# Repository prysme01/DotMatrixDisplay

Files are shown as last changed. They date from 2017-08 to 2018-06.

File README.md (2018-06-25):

# DotMatrixDisplay

Display messages to a DOT Matrix LED Display.
Message are sent to a MQTT server from any other application, the ESP8266 is subscribing to the channel and display messages depending on few parameters (animation, intensity, ...)

###### My use case
Displaying messages in the living room from my home automation solution (jeedom).

### Prerequisites

* ESP8266 (mine is Wemos D1 NodeMcu  ESP12F)
* DOT Matrix based on MAX7219
* OLED display (SSD1306 and SH1106 based 128x64 pixel) - optional
* MQTT server somewhere - preferred on your LAN for privacy
* Temperature sensor DS18B20 - optional
* Light sensor GL5516 - optional

### Features
* Display message from a MQTT server
* NTP client for date and time
* Temperature measurement
* LED matrix dimming based on light sensor
* Read a file to display text (TODO)
* more to come

### Usage
* Make sure your DotMatrix is properly configured according to [MAX72xx](https://github.com/MajicDesigns/MD_MAX72XX) (MAX72xx.h)
* Adapt the code (parameters, MQTT ipaddress)
* Drop the code to your ESP8266, third party libraries are included
* First time the ESP8266 should act as an access point (ESPxxxx), connect to it then go to http://192.168.4.1/ to configure your WIFI SSID/Password (STORE in EEPROM), then restart
* OLED should now display your IP on your network
* HTTP Command is available and describe at http://IP/command

### MQTT 
ESP8266 is subscribing to topic "jeedom/message" and expect this json syntax
```json
{
   "text": "My TEXT ",
   "priorite": 1,
   "lum": 15,
   "pos": 2,
   "eff_in": 1,
   "eff_out": 1,
   "speed": 25,
   "pause": 1000
}
```
-- text : the message to display
-- priority : TODO
-- lum : intensity of the LCD panel (1-15)
-- pos : 0-LEFT, 1-Center, 2-RIGHT
-- speed : speed of the animation (fps)
-- pause : time between entry and exit effect
-- eff_out : exit effect (same value as eff_in)
-- eff_in : entry effect
* 0 : SCROLL RIGHT
* 1 : SCROLL LEFT
* 2 : SCROLL UP
* 3 : SCROLL DOWN
* 4 : OPENING CURSOR
* 5 : CLOSING CURSOR
* 6 : WIPE
* 7 : MESH
* 8 : FADE
* 9 : PRINT (fixed message)
* 10 : BLIND
* 11 : SCAN HORIZONTAL 0
* 12 : SCAN HORIZONTAL 1
* 13 : SCAN VERITICAL 0
* 14 : SCAN VERITICAL 1

Prototype
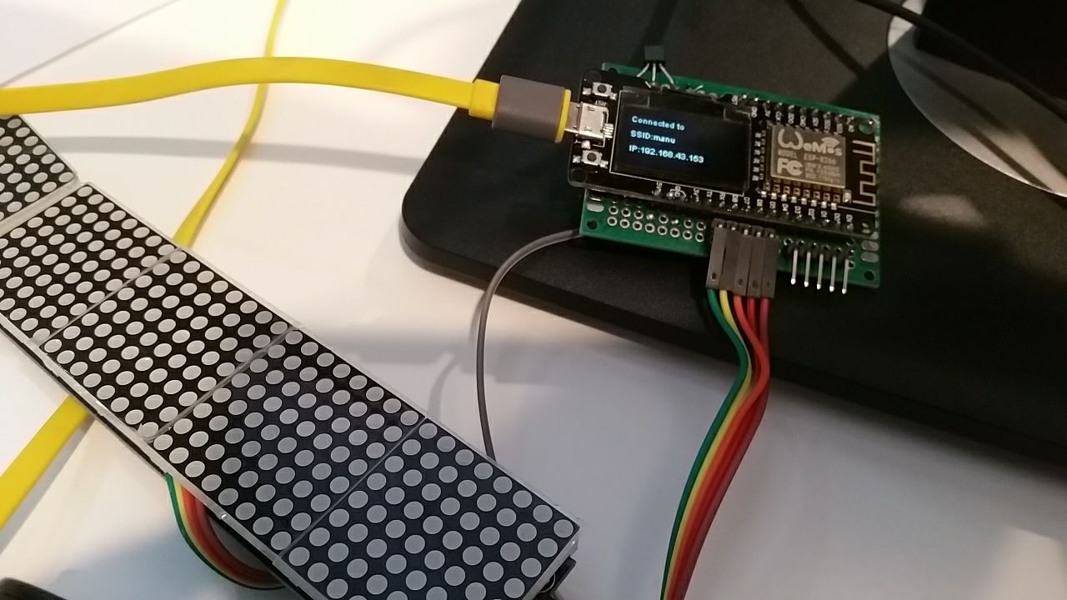
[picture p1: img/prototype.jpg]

Final and ugly soldering
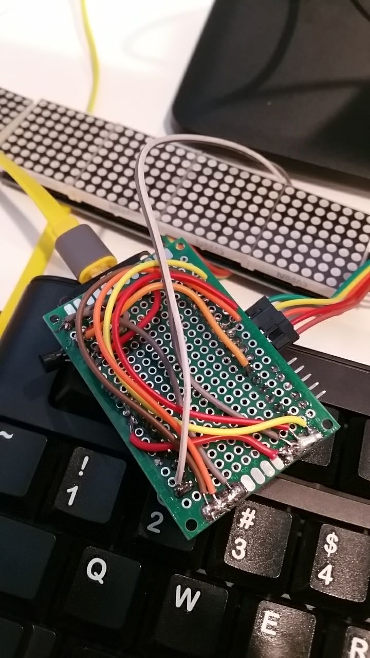
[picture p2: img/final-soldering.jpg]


SMALL VIDEO example HERE Video

### Sketch
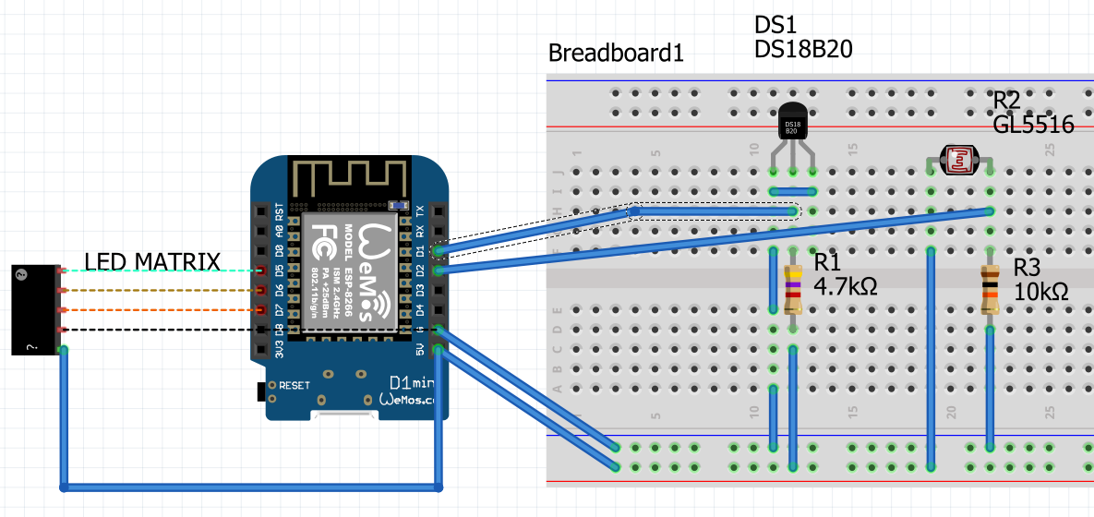
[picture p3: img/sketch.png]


The sketch is not good for the DS18B20, so check on google on how connect properly the DS18B20.
Also in the code the DS12B20 pin is set to D4 and on the image it's D1

## License

This project is licensed under the GPL License

## Acknowledgments

Thank you very much to [DIYDave](https://github.com/DIYDave/ScrollText-ESP8266) for his code and inspiration 

Libraries used, thanks to their respectives authors
* [MD_Parola](https://github.com/MajicDesigns/MD_Parola) DotMatrix management library
* [MAX72xx](https://github.com/MajicDesigns/MD_MAX72XX) Max7219 library
* [WifiManager](https://github.com/tzapu/WiFiManager) Wifi management
* [SSD1306](https://github.com/squix78/esp8266-oled-ssd1306) OLED library

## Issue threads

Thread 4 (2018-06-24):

wrong schematic?

fragolinux, 2018-06-24:
schematic seems wrong... there's no connection from ds18b20 to positive 3.3V, and there's a jumper right below it that connects vcc and gnd together... and data pin is connected to d1 in schematic, and to d4 in code...

fragolinux, 2018-06-24:
even display links are wrong between schematic and code, and the ds18b20 in code is linked to d4, in image to d1

prysme01, 2018-06-25:
yes sorry, I will remove the schematic, it has changed since and the code is not synced.

fragolinux, 2018-06-25:
so you'll republish an updated one, or at least publish a textual version in opening readme.md? thanks

Closed 2018-06-25.

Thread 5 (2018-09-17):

Support of P3 64x32 RGB LED Matrix?

hallard, 2018-09-17:
Awesome project,
It's not an issue, but I'm using JEEDOM also and got this nice [64x32 RGB LED Matrix](https://fr.aliexpress.com/item/P3-RGB-pixel-panel-HD-display-64x32-dot-matrix-p3-smd-rgb-led-module/32728985432.html) with custom adapter open sourced
https://github.com/hallard/WeMos-Matrix-Shield

Would be awesome to support this display, the library exists so may be it could be easy.
You can check out the original[project](https://www.instructables.com/id/Morphing-Digital-Clock/)

prysme01, 2018-09-17:
Hello charles,

I would be able to do it, but I need to have this matrix here to test it.
One day, maybe.

hallard, 2018-09-17:
Thanks,
Makes sense, I'm waiting for the V1.2 of my PCB adapters for this Matrix, I can send you one with a Wemos assembled if it can help to contrib ;-)

prysme01, 2018-09-17:
Sure I could work on it if you send it to me.

hallard, 2018-09-17:
Ok, get back back here when I receive the adapter boards

Closed 2019-07-29.

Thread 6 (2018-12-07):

great work but ...

bandric1, 2018-12-07:
Can you update the project it cannot be compiled with arduino when i try to compile get this error BearSSLHelpers.cpp:30:24: fatal error: StackThunk.h:

i have solved other library issues but cannot solve this one no matter what i do.

prysme01, 2018-12-07:
Hello, I don't have an arduino so this project has been done to be used on a weemos esp8266. I don't use anything in particular, but I won't be able to fix it. sorry.

bandric1, 2018-12-07:
i used arduino ide for compling i also use wemos but get that error

prysme01, 2018-12-07:
Let me check out my code and try it

bandric1, 2018-12-07:
I dont get u on this one, what do you mean?

prysme01, 2018-12-07:
I've just download a fresh Arduino IDE and my code from github it works fine.

Build options changed, rebuilding all
Sketch uses 337428 bytes (32%) of program storage space. Maximum is 1044464 bytes.
Global variables use 32304 bytes (39%) of dynamic memory, leaving 49616 bytes for local variables. Maximum is 81920 bytes.

All I've done is :
Adding a new board in Arduino IDE ( copy the following and paste into your Preferences dialog and select OK: http://arduino.esp8266.com/stable/package_esp8266com_index.json  )
Select Board Weemos D1

Copy the library folder from my code into C:\Users\esale\Documents\Arduino\libraries
Compile complain about WifiManager error, I've update the WifiManager from tzapu to 0.14.0 and it compile fine.

I don't understand where you get this error from BearSSLHelpers.

bandric1, 2018-12-07:
Ok i guess ive done some stupit things with arduino and it knocked me out.
Thanks.

bandric1, 2018-12-07:
There is one more question i use credentials to login to my mqtt. I didnt find anywhere in .ino exept the ip and topic.

prysme01, 2018-12-07:
you are right, I did not manage credentials, the topic has to be public, so no user/password.

Closed 2019-07-29.

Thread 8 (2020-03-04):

Problems with Compiling

capitaenz, 2020-03-04:
Hi,

I have already tried various things, but unfortunately no success.
I get this error when compiling:

> exit status 1
> 'PA_SCAN_HORIZ0' was not declared in this scope

I tried different versions of Arduino IDE, different versions of the libraries, ...
What else can I try?

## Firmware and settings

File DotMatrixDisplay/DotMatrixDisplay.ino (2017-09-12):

// Configure is you want to use OLED display or DEBUG to serial
// Comment option to disable
#define USE_OLED_DISPLAY 
#define USE_LIGHT_SENSOR
#define USE_DEBUG 1

#include <MD_Parola.h>          // https://github.com/MajicDesigns/MD_parola
#include <MD_MAX72xx.h>         // https://github.com/MajicDesigns/MD_MAX72XX
#include <MD_MAX72xx_lib.h>
#include <SPI.h>
#include "utf8_font.h"
//#include "utf8_tools.c"

#ifdef USE_OLED_DISPLAY
  #include <Wire.h>
  #include <brzo_i2c.h>
  #include <OLEDDisplay.h>
  #include <OLEDDisplayFonts.h>
  #include <OLEDDisplayUi.h>
  #include <SSD1306.h>
  #include <SSD1306Spi.h>
  #include <SSD1306Brzo.h>
  #include <SSD1306Wire.h>
  #include "res.h"                  // Picture resources in the sketch directory
#endif

#include <DNSServer.h>

#include <ESP8266WiFi.h>
#include <ESP8266WiFiAP.h>
#include <ESP8266WiFiGeneric.h>
#include <ESP8266WiFiMulti.h>
#include <ESP8266WiFiScan.h>
#include <ESP8266WiFiSTA.h>
#include <ESP8266WiFiType.h>
#include <WiFiClient.h>
#include <WiFiClientSecure.h>
#include <WiFiServer.h>
#include <WiFiUdp.h>
#include <WiFiManager.h>          //WiFi Configuration Magic https://github.com/tzapu/WiFiManager 
#include <EEPROM.h>               // Library for handle teh EEPROM

#include <TimeLib.h>
#include <NtpClientLib.h>

#include <OneWire.h>
#include <DallasTemperature.h>

#include <ArduinoJson.h>
#include <PubSubClient.h>

// ESP8266 PIN configuration
#define CLK_PIN   D5  // Matrix CLK
#define DATA_PIN  D7  // Matrix DIN
#define CS_PIN    D6  // Matrix DS
#define DS18B20BUS D4 // OneWire Dallas DS18B20 PIN

#define MAX_DEVICES 8 // Number of LED MATRIX module

// DS18B20 Temperature sensor
OneWire oneWire(DS18B20BUS);
DallasTemperature DS18B20(&oneWire);

long millis_temperature;                                                    // Use in the loop to store execution time
long millis_lightsensor;                                                    // Use in the loop to store execution time

// PAROLA 
uint8_t parolaCurrentType = 0;
uint8_t frameDelay = 25; // default frame delay value
//char parolaCurrentMessage[256] = "";
char parolaCurrentMessage[120];
textEffect_t parolaEffectIn;
textEffect_t parolaEffectOut;
textPosition_t parolaPosition;
int parolaAnimationSpeed;
int parolaPause;
bool parolaIntensityManagedBySensor = true;                                 // light sensor management on/off
bool newMessageAvailable = false;
int LIGHT_SENSOR_POLLING=60*1000;                                           // Wait 5 sec to adjust LED matrix intensity based on light sensor
MD_Parola parola = MD_Parola(CS_PIN, MAX_DEVICES);                          // HARDWARE SPI for dot matrix display
uint8_t pin_led = 16;

// MQTT CONFIGURATION
const char* MQTT_TOPIC_MESSAGE = "jeedom/message";                          // MQTT topic to subscribe for message
const char* MQTT_TOPIC_SENSOR  = "jeedom/ESP8266_LED_MATRIX_BOX/sensors";   // MQTT topic to publish temperature
const char* MQTT_TOPIC_SENSOR_DEVICE  = "ESP8266_LED_MATRIX_BOX";           // MQTT topic to publish temperature
const char* MQTT_CLIENT_ID ="ESP32Client";                                  // MQTT client id needed to get offline messages during reconnexion | not working mqtt lib doesnot support clean session
const IPAddress MQTT_BROKER_IP(37,187,1,120);                               // MQTT BROKER IP address
const int  MQTT_BROKER_PORT = 1883;                                         // MQTT BROKER port
const int MQTT_POLLING_SENSOR = 15*60*1000;                                 // MQTT polling delay between sending temperature to jeedom in millisec

WiFiClient wifiClient;
WiFiManager wifiManager;
PubSubClient mqttclient(wifiClient);

#ifdef USE_OLED_DISPLAY
  SSD1306Brzo  display(0x3c, D1, D2);
#endif 



uint8_t utf8Ascii(uint8_t ascii)
{
  static uint8_t cPrev;
  uint8_t c = '\0';

  if (ascii < 0x7f)   // Standard ASCII-set 0..0x7F, no conversion
  {
    cPrev = '\0';
    c = ascii;
  }
  else
  {
    switch (cPrev)  // Conversion depending on preceding UTF8-character
    {
    case 0xC2: c = ascii;  break;
    case 0xC3: c = ascii | 0xC0;  break;
    case 0x82: if (ascii==0xAC) c = 0x80; // Euro symbol special case
    }
    cPrev = ascii;   // save last char
  }

  PRINTX("\nConverted 0x", ascii);
  PRINTX(" to 0x", c);

  return(c);
}

void utf8Ascii(char* s)
{
  uint8_t c, k = 0;
  char *cp = s;

  PRINT("\nConverting: ", s);

  while (*s != '\0')
  {
    c = utf8Ascii(*s++);
    if (c != '\0')
      *cp++ = c;
  }
  *cp = '\0';   // terminate the new string
}


void configModeCallback (WiFiManager *myWiFiManager) {
  #if USE_DEBUG
    Serial.println("Entered config mode");
    Serial.println(WiFi.softAPIP());
    Serial.println(myWiFiManager->getConfigPortalSSID());
  #endif
  
  #ifdef USE_OLED_DISPLAY
    display.drawString(0, 0, "Entering Config Mode" );
    display.drawString(0, 20, "SSID:"+myWiFiManager->getConfigPortalSSID() );
    display.drawString(0, 40,"IP:" + WiFi.softAPIP().toString() );
    display.display();
  #endif

  parola.print("AP|MODE");
}

#ifdef USE_OLED_DISPLAY
/**
 * Display LOGO for 1 second (Logo is declared in res.h)
 * format XBM done with GIMP 128 pixels x 64 pixels Black and White
 */
void OLEDWelcome() {
  display.drawXbm(0 , 0, Logo_width, Logo_height, xbm_bits);
  display.display();
  delay(1000);
  display.clear();
}
#endif

/**
 * Setup code, run once a startup
 */
void setup() {
  
  #if USE_DEBUG
    Serial.begin(115200);
  #endif

  // Start DS18B20 measurement
  DS18B20.begin();

  //pinMode(A0,INPUT);
  
  //pinMode(LED_BUILTIN,OUTPUT);                        // configure the builtin led to OUTPUT mode
  //digitalWrite(LED_BUILTIN,!digitalRead(pin_led));  // switch the status (values can be LOW or HIGH)

  #ifdef USE_OLED_DISPLAY
    // OLED Init
    display.init();
    display.clear();
    //display.setContrast(55);
    display.setFont(ArialMT_Plain_10);
    display.setTextAlignment(TEXT_ALIGN_LEFT);
    OLEDWelcome();
  #endif
  
  // Dot Matrix init
  parola.begin(); 
  parola.displayClear();
  parola.displaySuspend(false);
  parola.setIntensity(5);  // Restore last intensity value saved from EEPROM
  parola.setFont(ExtASCII);
  parola.setTextAlignment(PA_CENTER);
  //parola.setCharSpacing(1);
  
  wifiManager.setAPCallback(configModeCallback);
  //wifiManager.setConfigPortalTimeout(TIMEOUT_PORTAL);
  Serial.println("Wifi.autoConnect start");
  if(!wifiManager.autoConnect()) {
    parola.displayText ("WIFI not working", PA_CENTER, 15, 1000, PA_OPENING_CURSOR , PA_OPENING_CURSOR );
    //reset and try again, or maybe put it to deep sleep
    //ESP.reset();
    //delay(5000);
  } else {
    parola.displayText ("WIFI Ready", PA_CENTER, 15, 1000, PA_OPENING_CURSOR , PA_OPENING_CURSOR );
    NTP.begin("pool.ntp.org", 1, true);
    NTP.setInterval(3600);
    NTP.onNTPSyncEvent([](NTPSyncEvent_t error) {
      if (error) {
        Serial.print("Time Sync error: ");
        if (error == noResponse)
          Serial.println("NTP server not reachable");
        else if (error == invalidAddress)
          Serial.println("Invalid NTP server address");
        }
      else {
        Serial.print("Got NTP time: ");
        Serial.println(NTP.getTimeDateString(NTP.getLastNTPSync()));
      }
    });
    #ifdef USE_OLED_DISPLAY
      display.drawString(0, 0, "Connected to " );
      display.drawString(0, 20, "SSID:"+WiFi.SSID() );
      display.drawString(0, 40,"IP:" + WiFi.localIP().toString() );
    #endif
  }
  
  // Print the IP address
  #if USE_DEBUG
    Serial.println(WiFi.localIP());
  #endif

  #ifdef USE_OLED_DISPLAY
    // Flush OLED display
    display.display();  
  #endif

  // Get first sync
  NTP.getTimeDateString();
  
  // init time
  millis_temperature = millis();
  millis_lightsensor = millis();

  mqttclient.setServer(MQTT_BROKER_IP, MQTT_BROKER_PORT);
  mqttclient.setCallback(mqttCallback);
}
boolean reconnect() {
  if (mqttclient.connect(MQTT_CLIENT_ID)) {
    mqttclient.subscribe(MQTT_TOPIC_MESSAGE);
    Serial.println("mqtt connected.");
  }
  return mqttclient.connected();
}

textEffect_t parseAnimation(int anim) {
  // unknown default animation
  textEffect_t choosenAnimation = PA_SCROLL_RIGHT;
  switch (anim){
          case 0: 
            choosenAnimation = PA_SCROLL_RIGHT;
            break;    
          case 1: 
            choosenAnimation = PA_SCROLL_LEFT;
            break;
          case 2:
            choosenAnimation = PA_SCROLL_UP;
            break;
          case 3:
            choosenAnimation =  PA_SCROLL_DOWN;
            break;
          case 4:
            choosenAnimation = PA_OPENING_CURSOR;
            break;
          case 5:
            choosenAnimation = PA_CLOSING_CURSOR;
            break;
          case 6:
            choosenAnimation = PA_WIPE_CURSOR;
            break;
          case 7:
            choosenAnimation = PA_MESH;
            break;
          case 8:
            choosenAnimation = PA_FADE;
            break;
          case 9:
            choosenAnimation = PA_PRINT;
            break;
          case 10:
            choosenAnimation = PA_BLINDS;
            break;
          case 11:
            choosenAnimation = PA_SCAN_HORIZ0;
            break;    
          case 12:
            choosenAnimation = PA_SCAN_HORIZ1;
            break; 
          case 13:
            choosenAnimation = PA_SCAN_VERT0;
            break; 
          case 14:
            choosenAnimation = PA_SCAN_VERT1;
            break;                                                                                                                               
        }
    return choosenAnimation;
}

void mqttCallback(char* topic, byte* payload, unsigned int length) {
  Serial.println("mqttCallback start");
  // Allocate the correct amount of memory for the payload copy
  byte* payloadcopy = (byte*)malloc(length);
  // Copy the payload to the new buffer
  memcpy(payloadcopy,payload,length);
  
  StaticJsonBuffer<512> jsonBuffer;
  JsonObject& root = jsonBuffer.parseObject((char*)payloadcopy);
  // Test if parsing succeeds.
  if (!root.success()) {
    Serial.println("parseObject() failed");
    return;
  } else {
    // Dealing with TEXT
    newMessageAvailable = true;
    if (root.containsKey("text")) {
      if (root["text"] != "") {
        String text = root["text"].as<String>();
        text.toCharArray(parolaCurrentMessage, text.length()+1); 
        utf8Ascii(parolaCurrentMessage);
        
      } else {
        strcpy (parolaCurrentMessage, "empty text");
      }
    } else {
      strcpy (parolaCurrentMessage, "miss text tag");
    }
    
    // Dealing with intensity
    parolaIntensityManagedBySensor = true;
    if (root.containsKey("lum")) {
      if ( root["lum"] != "") {
        // set specific intensity
        parola.setIntensity((int)root["lum"]);
        parolaIntensityManagedBySensor = false;
      }
    }
    // Dealing with text position
    // default CENTER
    parolaPosition = PA_CENTER;
    if (root.containsKey("pos")) {
      if ( root["pos"] != "") {
        int pos = (int)root["pos"];
        switch (pos) {
          case 0:parolaPosition=PA_LEFT;break;
          case 1:parolaPosition=PA_CENTER;break;
          case 2:parolaPosition=PA_RIGHT;break;
        }
      }
    }
    // dealing with animation IN
    parolaEffectIn = PA_SCROLL_RIGHT;
    // Dealing with intensity
    if (root.containsKey("eff_in")) {
      if ( root["eff_in"] != "") {
        int anim = (int)root["eff_in"];
        parolaEffectIn = parseAnimation(anim);
      }
    }

    // dealing with animation OUT
    parolaEffectOut = PA_SCROLL_RIGHT;
    // Dealing with intensity
    if (root.containsKey("eff_out")) {
      if ( root["eff_out"] != "") {
        int anim = (int)root["eff_out"];
        parolaEffectOut = parseAnimation(anim);
      }
    }
    
    // dealing with speed
    parolaAnimationSpeed = 15;
    if (root.containsKey("speed")) {
      if ( root["speed"] != "") {
        parolaAnimationSpeed = (int)root["speed"];
      }
    }
    
    // dealing with pause
    parolaPause = 1000;
    if (root.containsKey("pause")) {
      if ( root["pause"] != "") {
        parolaPause = (int)root["pause"];
      }
    }
  }
  
  // Free the memory
  free(payloadcopy);
}

/**
 * Adjust LED matrix luminosity according to the Light sensor
 */
void adjustLuminosity() {
  #ifdef USE_LIGHT_SENSOR
    int photocellReading = analogRead(A0);
    if (photocellReading < 600) {
      //Serial.println(" - Noir");
      parola.setIntensity(1);
    } else if (photocellReading < 700) {
      //Serial.println(" - Sombre");
      parola.setIntensity(3);
    } else if (photocellReading < 800) {
      //Serial.println(" - Lumiere");
      parola.setIntensity(5);
    } else if (photocellReading < 1000) {
      //Serial.println(" - Lumineux");
      parola.setIntensity(7);
    } else {
      //Serial.println(" - Tres lumineux");
      parola.setIntensity(15);
    }
    Serial.print("Adjusting luminosity to ");
    Serial.println(photocellReading);
  #endif
}

void sendTemperatureToMQTT() {

  DS18B20.requestTemperatures();
  
  // send json to mqtt
  StaticJsonBuffer<300> JSONbuffer;
  JsonObject& JSONencoder = JSONbuffer.createObject();
  
  JSONencoder["device"] = MQTT_TOPIC_SENSOR_DEVICE;
  JSONencoder["sensorType"] = "TemperatureSensor";
  JSONencoder["temperature"] = DS18B20.getTempCByIndex(0);

  char JSONmessageBuffer[100];
  JSONencoder.printTo(JSONmessageBuffer, sizeof(JSONmessageBuffer));
 
  if (mqttclient.publish(MQTT_TOPIC_SENSOR, JSONmessageBuffer) == true) {
    Serial.println(JSONmessageBuffer);  
  } else {
    Serial.println("Error sending message");
  }
}

void loop() {

  
  if (parola.displayAnimate())  {// True if animation ended

    if (newMessageAvailable) {
      char newMessage[120];
      strcpy(newMessage,parolaCurrentMessage);
      Serial.println("new msg available : ");
      Serial.print("text : ");
      Serial.println(newMessage);
      Serial.print("parolaPosition : ");
      Serial.println(parolaPosition);
      Serial.print("parolaAnimationSpeed : ");
      Serial.println(parolaAnimationSpeed);
      Serial.print("parolaPause : ");
      Serial.println(parolaPause);
      Serial.print("parolaEffectIn : ");
      Serial.println(parolaEffectIn);
      Serial.print("parolaEffectOut : ");
      Serial.println(parolaEffectOut);

      parola.displayText(newMessage, parolaPosition,parolaAnimationSpeed,parolaPause,parolaEffectIn,parolaEffectOut );
      //parola.displayScroll(newMessage, parolaPosition,parolaEffectIn,parolaAnimationSpeed );
      newMessageAvailable = false;
    }
    //parola.displayReset();
    
    if (parolaIntensityManagedBySensor && ((millis()-millis_lightsensor) > LIGHT_SENSOR_POLLING) ) {
      adjustLuminosity();
      millis_lightsensor = millis();
    }
    
    if (!mqttclient.connected()) {
      reconnect();
    } else {
      // Client connected
      mqttclient.loop();
    }

    // Every MQTT_POLLING_SENSOR
    if((millis() - millis_temperature) > MQTT_POLLING_SENSOR) {
        sendTemperatureToMQTT();
        millis_temperature = millis(); 
    }
  }
}

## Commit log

2017-08-31 add temperature sensor
2017-08-31 Add Light sensor dimming
2017-08-31 Add Electrical Sketch
    [Sketch.fzz]
2017-09-01 starting implementation of MQTT to replace HTTP command
    [Sketch.fzz]
2017-09-05 Remove webserver, MQTT working
    [Sketch.fzz]
2017-09-06 Clean and fix temperature routine
    [DotMatrixDisplay.ino]
2017-09-12 Should fix UTF8 issue, not tested
    [DotMatrixDisplay.ino]
